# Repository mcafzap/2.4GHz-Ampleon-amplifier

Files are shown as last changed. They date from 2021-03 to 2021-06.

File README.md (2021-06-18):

# This amplifier is based on the Ampleon BCP2425M9X2S250-1 pallet

The bias circuit is taken from Ampleon's application note AN10900. There is an MSP430G2553 processor and an I2C 1.3" OLED display and 2 digital current monitors using the TLI4970. Unfortunately this current measurement device is end-of life, but it remains the best for resolving 6.25mA and measuring up to 25A. The display monitors voltage & current of each stage, sets the bias of each stage and shows the total power used.

Output protection is provided by a 100W isolator from Bert Modderman (pe1rki.com)
A 30v, 10A supply should give about 150W maximum - more than adequate for Q0-100 access. This pallet has 30dB of gain but a pre-amp will likely be required - the Amsat kit or a cheap shielded Chinese type. The circuit board uses an LM2596 dc-dc module. This can supply 12v for fans and/or the pre-amp or any voltage may be set to suit these devices. A lower voltage will lower the stress on the 3.3v linear regulator.

I used Kicad to draw/plot the circuit board and had them manufactured by JLCPCB. The program was written and tested on TI's Code Composer Studio but Energia may be used. 
The metal work was designed on FreeCAD and can be made from stock Al bar (10mm x 20mm) and Al sheet (2mm). The heatspreader is 10mm x 100mm x 72mm Cu. This is mounted on an Al heatsink approximately 250mm x 200mm x 40mm; it does not seem to require any fans.

Remember this is high frequency so everything must be kept short or shielded and properly 50 ohm terminated.

Thanks go to Vincent(M0LCR), Mike(G4VSS) and Brian(G4EWJ) for software/hardware advice but thanks are especially owed to Anthony Tognarelli of Waterfield Electronics Ltd. (waterfieldelectronics.com) for providing the pallets.

If I were to do this again? I'd simply use multi-turn presets to set the bias levels, (10K across a 3.3v supply). Much of the circuitry is concerned with displaying little-used data like power input and bias currents - once set, these are never changed.

vcloseamp
closeAMP
full amp

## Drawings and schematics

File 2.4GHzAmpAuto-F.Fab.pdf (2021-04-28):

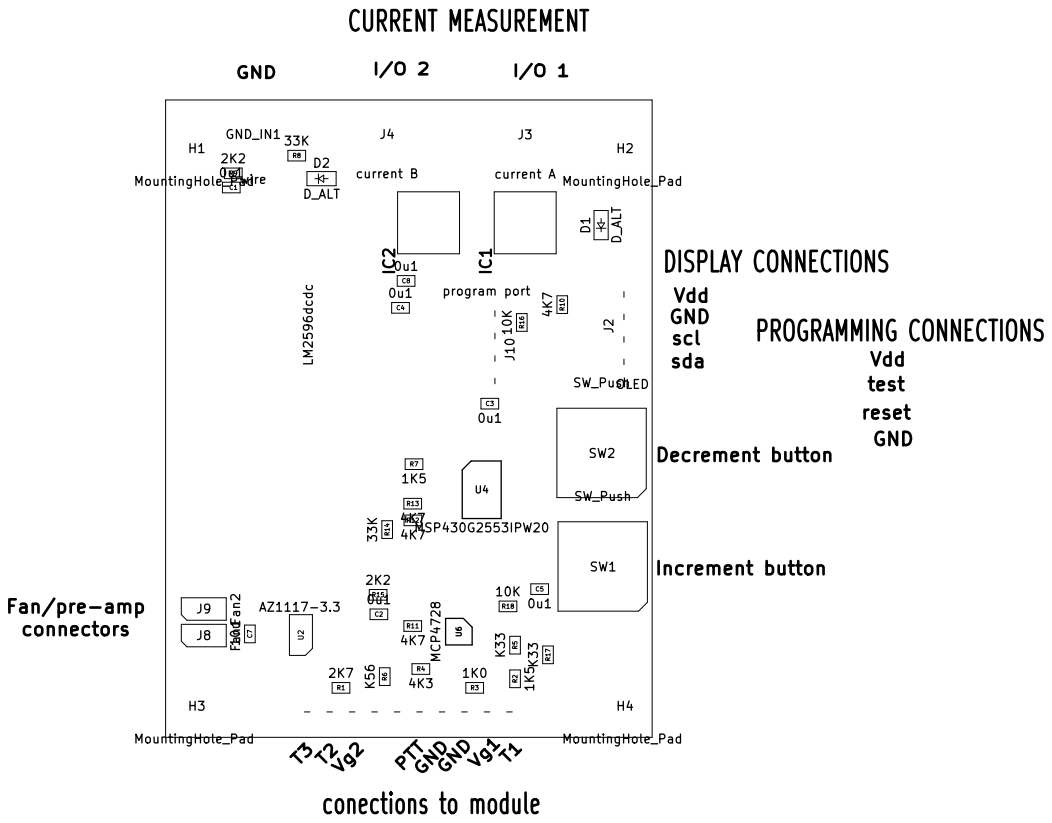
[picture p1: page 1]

Increment button Decrement button

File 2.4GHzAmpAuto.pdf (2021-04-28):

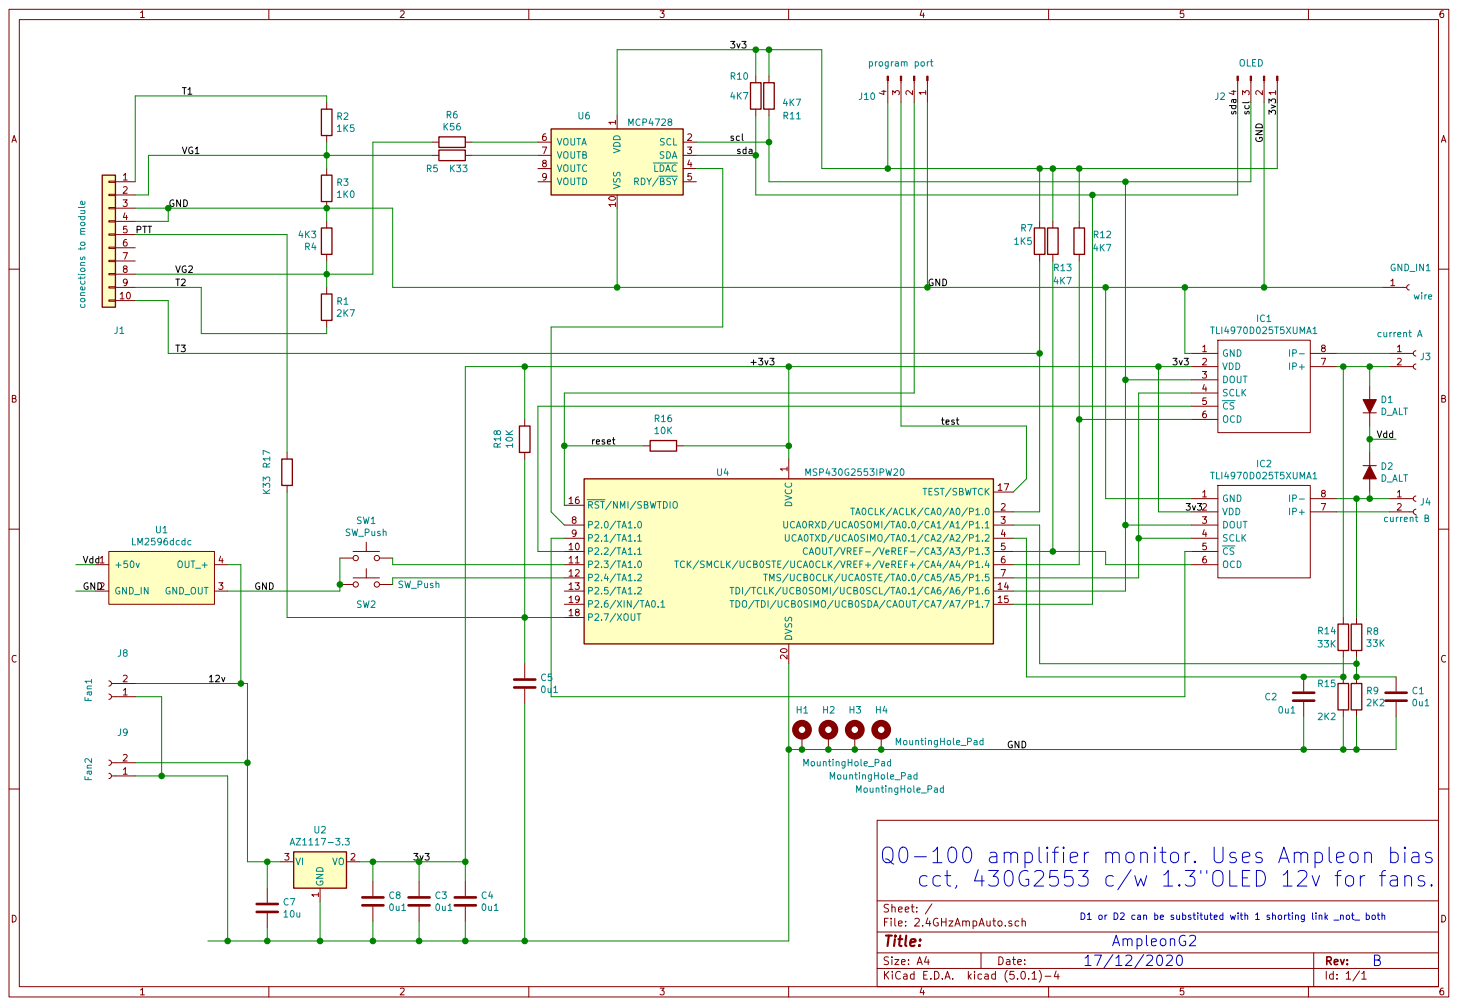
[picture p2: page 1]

1 P2.2/TA1.1 10 P2.3/TA1.0 11 P2.4/TA1.2 12 P2.5/TA1.2 13 TDI/TCLK/UCB0SOMI/UCB0SCL/TA0.1/CA6/A6/P1.6 14 TDO/TDI/UCB0SIMO/UCB0SDA/CAOUT/CA7/A7/P1.7 15 RST/NMI/SBWTDIO 16 TEST/SBWTCK 17 P2.7/XOUT 18 P2.6/XIN/TA0.1 19 TA0CLK/ACLK/CA0/A0/P1.0 2 DVSS 20 UCA0RXD/UCA0SOMI/TA0.0/CA1/A1/P1.1 3 UCA0TXD/UCA0SIMO/TA0.1/CA2/A2/P1.2 4 CAOUT/VREF-/VeREF-/CA3/A3/P1.3 5 TCK/SMCLK/UCB0STE/UCA0CLK/VREF+/VeREF+/CA4/A4/P1.4 6 TMS/UCB0CLK/UCA0STE/TA0.0/CA5/A5/P1.5 7 P2.0/TA1.0 8 P2.1/TA1.1 9 U4 MSP430G2553IPW20 R12

GND 1 VDD 2 DOUT 3 SCLK 4 CS 5 OCD 6

Q0-100 amplifier monitor. Uses Ampleon bias
cct, 430G2553 c/w 1.3"OLED 12v for fans.

File: 2.4GHzAmpAuto.sch Sheet: / GND

AmpleonG2

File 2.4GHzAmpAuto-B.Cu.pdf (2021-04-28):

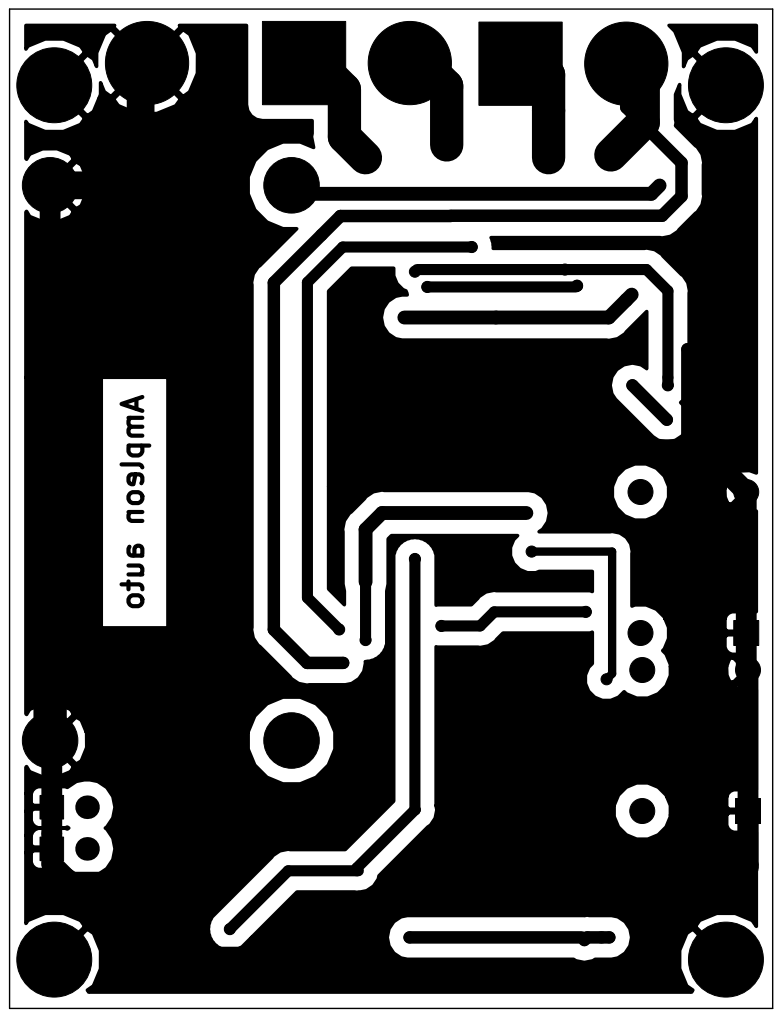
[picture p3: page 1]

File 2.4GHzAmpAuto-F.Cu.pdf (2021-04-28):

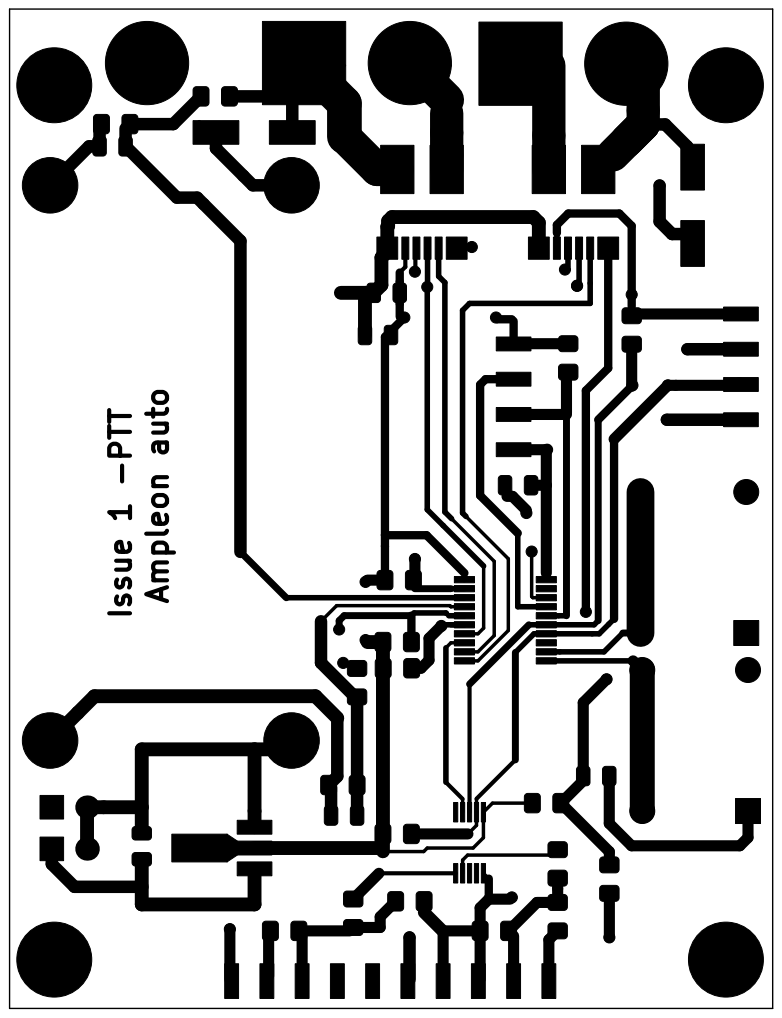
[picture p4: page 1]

Issue 1 -PTT Ampleon auto

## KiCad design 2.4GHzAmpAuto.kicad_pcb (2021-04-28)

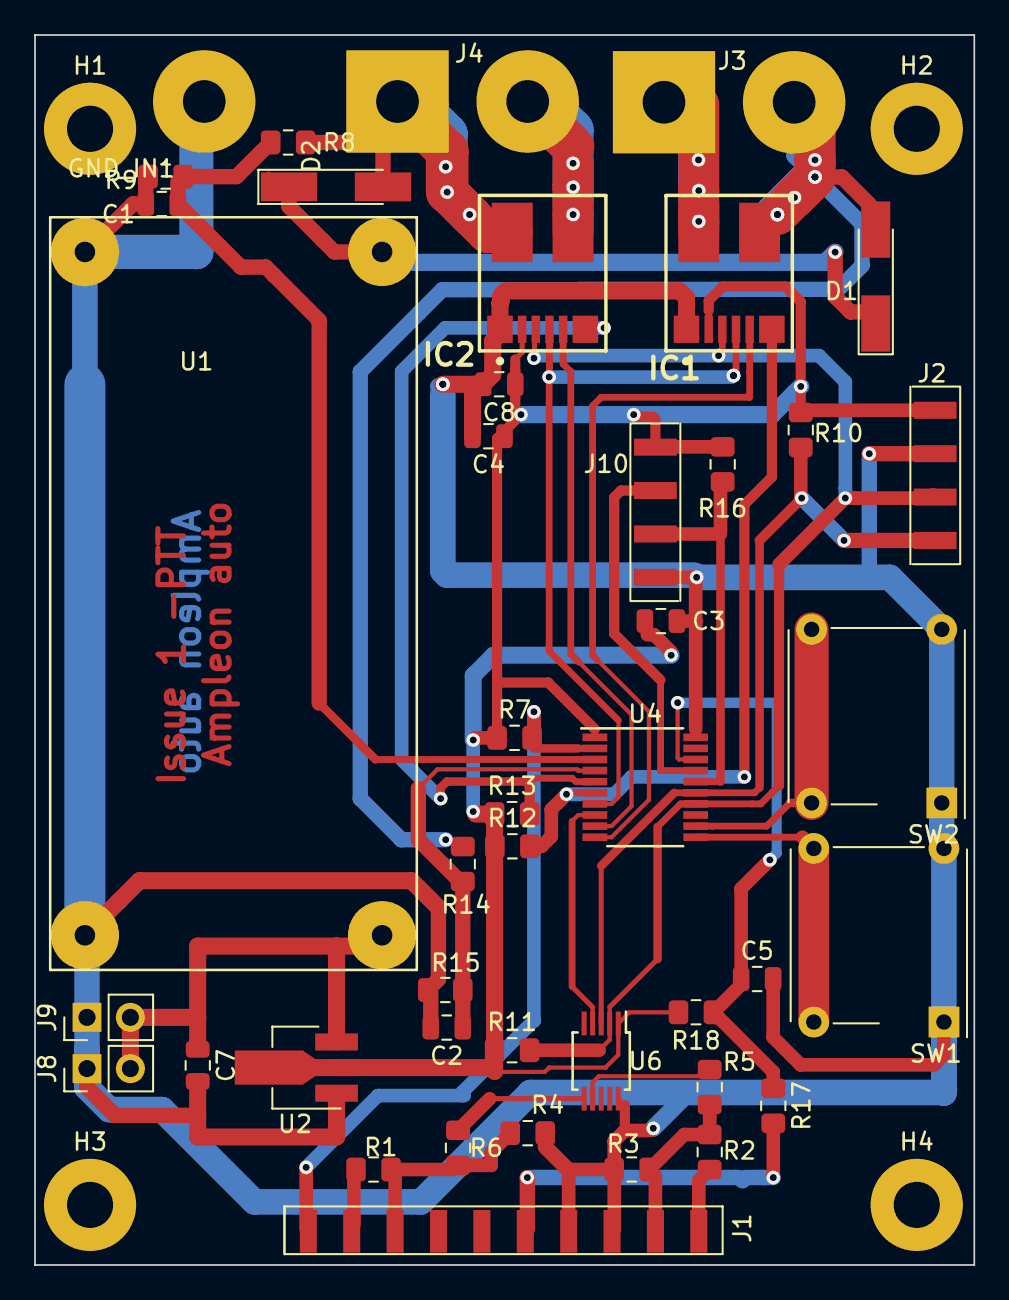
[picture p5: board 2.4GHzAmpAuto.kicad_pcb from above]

Board: 2 copper layers, 55.0 x 72.0 mm, 47 parts (0 on the bottom side), 31 nets.

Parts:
C1, C2, C3, C4, C5, C8: 0u1; C_0805_2012Metric
C7: 10u; C_0805_2012Metric
D1, D2: D_ALT; D_MiniMELF_Handsoldering
GND_IN1: wire; SolderWirePad_1x01_Drill2.5mm
H1, H2, H3, H4: MountingHole_Pad; MountingHole_2.7mm_M2.5_Pad
IC1, IC2: TLI4970D025T5XUMA1; PG-TISON-8-1
J1: conections to module; Harwin_M20-89010xx_1x10_P2.54mm_Horizontal
J2: OLED; 1x04_P2.54mm_Pads
J3: current A; SolderWirePad_1x02_P7.62mm_Drill2.5mm
J4: current B; SolderWirePad_1x02_P7.62mm_Drill2.5mm
J8: Fan1; PinHeader_1x02_P2.54mm_Vertical
J9: Fan2; PinHeader_1x02_P2.54mm_Vertical
J10: program port; 1x04_P2.54mm_Pads
R1: 2K7; R_0805_2012Metric_Pad1.15x1.40mm_HandSolder
R2, R7: 1K5; R_0805_2012Metric_Pad1.15x1.40mm_HandSolder
R3: 1K0; R_0805_2012Metric_Pad1.15x1.40mm_HandSolder
R4: 4K3; R_0805_2012Metric_Pad1.15x1.40mm_HandSolder
R5, R17: K33; R_0805_2012Metric_Pad1.15x1.40mm_HandSolder
R6: K56; R_0805_2012Metric_Pad1.15x1.40mm_HandSolder
R8, R14: 33K; R_0805_2012Metric_Pad1.15x1.40mm_HandSolder
R9, R15: 2K2; R_0805_2012Metric_Pad1.15x1.40mm_HandSolder
R10, R11, R12, R13: 4K7; R_0805_2012Metric_Pad1.15x1.40mm_HandSolder
R16, R18: 10K; R_0805_2012Metric_Pad1.15x1.40mm_HandSolder
SW1, SW2: SW_Push; SW_MEC_5GTH9
U1: LM2596dcdc; LM2596_dc-dc_module
U2: AZ1117-3.3; SOT-89-3_Handsoldering
U4: MSP430G2553IPW20; TSSOP-20_4.4x6.5mm_P0.65mm
U6: MCP4728; MSOP-10_3x3mm_P0.5mm

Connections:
/12v: C7.1, J8.2, J9.2, U1.4, U2.3
/+3v3: C3.1, C4.1, C8.1, IC1.2, IC2.2, J2.1, J10.4, R7.1, R10.1, R11.1, R12.1, R13.1, R16.1, R18.2, U2.2, U4.1, U6.1
/GND: C1.2, C2.2, C3.2, C4.2, C5.2, C7.2, C8.2, GND_IN1.1, H1.1, H2.1, H3.1, H4.1, IC1.1, IC2.1, J1.3, J1.4, J2.2, J8.1, J9.1, J10.1, R3.2, R4.2, R9.2, R15.2, SW1.1, SW2.1, U1.2, U1.3, U2.1, U4.20, U6.10
/PTT: J1.5, R17.2
/T1: J1.1, R2.1
/T2: J1.9, R1.2
/T3: J1.10, R7.2, U4.2
/VG1: J1.2, R2.2, R3.1, R5.2
/VG2: J1.8, R1.1, R4.1, R6.2
/Vdd: D1.1, D2.1, U1.1
/reset: J10.2, R16.2, U4.16
/scl: IC1.3, IC2.3, J2.3, R11.2, U4.14, U6.2
/sda: J2.4, R10.2, U4.15, U6.3
/test: J10.3, U4.17
unnamed: C1.1, R8.2, R9.1, U4.3
unnamed: C2.1, R14.2, R15.1, U4.4
unnamed: C5.1, R17.1, R18.1, U4.18
unnamed: D1.2, IC1.7, J3.2, R14.1
unnamed: D2.2, IC2.8, J4.1, R8.1
unnamed: IC1.4, IC2.4, U4.7
unnamed: IC1.5, U4.10
unnamed: IC1.6, R12.2, U4.6
unnamed: IC1.8, J3.1
unnamed: IC2.5, U4.9
unnamed: IC2.6, R13.2, U4.5
unnamed: IC2.7, J4.2
unnamed: R5.1, U6.7
unnamed: R6.1, U6.6
unnamed: SW1.2, U4.11
unnamed: SW2.2, U4.12
unnamed: U4.8, U6.4

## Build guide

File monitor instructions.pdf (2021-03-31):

## Amplifier Monitor

The functon of this circuit is to set the bias currents of the 2 actve devices on the Ampleon BPC2425M9X2S250 pallet and monitor the current and power taken by this amplifer and provide a 12 volt supply for 2 x 50mm fans forced cooling. Some of the circuit is taken from the Ampleon datasheet.
There is a 1.3” OLED display and 2 pushbutons. The display has 2 modes, normally it shows the voltage and current being taken by the module along with the total input power. When setng the bias currents, one of the 2 bias levels is shown instead of the power.
The current monitors are fully isolated and can be connected in either polarity. They have a range of +/-25A and the resoluton is 6.25mA so the display will change in about 6mA steps (6, 12, 18, 25 ...).

Wiring.
At one end the connectons are arranged to provide a one-to-one correlaton to the module. The board needs a ground (0v) connecton; it can take its supply voltage (30v) from either current monitor. These current monitors may be connected in any polarity and either may be used for the 2 stages.

Removal of Ofset.
At frst switch-on there may be an ofset of 1 or 2 bits which will manifest itself as +/-0.006 or 0.012; this can be removed (only once per switch-on) by pressing both butons together.

Bias setng mode.
This is entered by holding down one of the butons whilst applying the power. Which buton is held is down determines which bias setng will be adjusted.
The bias levels can range from 0 to 3.300 volts in 1mV steps. Note that there is a resistor divider and thermistor circuit before this voltage goes to the module, so this is not the value output to the module.
Pressing any buton will either increment or decrement the bias value;

holding the buton will cause the value to change rapidly. Monitor the current value whilst adjustng the bias untl it is set correctly 50mA for the frst stage and 25mA the output stage. Do not turn-of the circuit untl the display reverts to the Input Power (there is a 10 second tmeout) as the bias value is not saved untl then.

Push-to-Talk.
An additonal switch may be used to disable the bias outputs. This requires a connecton to pin 18 of the microprocessor, a series resistor and a decoupling capacitor.
However, the quiescent power is only 2 wats so this may be unnecessary.

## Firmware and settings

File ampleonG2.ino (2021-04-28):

#include <SPI.h>
#include <Wire.h>
#include <U8x8lib.h>
#include <OneWire.h>
#include "MspFlash.h"

#define flash SEGMENT_D
// Pins usage
int CS1 = P2_1;
int CS2 = P2_2;
int SCL = P1_6;
int SDA = P1_7;

int ThermistorPin = A0;
int VoltagePinA = A1;
int VoltagePinB = A2;
const int Button1 = P2_3;
const int Button2 = P2_4;
const int Button3 = 18; //P2_7 on MSP430G2553

const uint16_t degree[] = { 576, 563, 550, 537, 524, 511, 498, 485, 473, 460,
                            448, 435, 423, 412, 400, 388, 377, 366, 355, 344,
                            334, 324, 314, 304, 295, 285, 276, 259, 250, 242,
                            234, 227, 219, 212, 205, 198, 192, 185, 179, 173,
                            167, 161, 156, 151, 146, 141, 137, 132, 128, 124,
                            119, 116, 112, 108, 105, 101, 98, 95, 92, 89, 86,
                            83, 81, 78, 76, 73, 71, 69, 66, 65, 62, 60, 59, 57,
                            55 };
// 76 values 20 - 95C
//const uint16_t degree[] = { 511, 448, 388, 334, 285, 242, 205, 173, 146, 124,
//                            105, 89, 76, 65, 55 };
// 15 values
// 21 degrees = (511-448/5) + 511 ~ 498.4
// Variables
uint8_t x, neg;
uint8_t setMode = 0, zeroBias = 0, offsetRemoval = 0;
char SerBuf[8];
//unsigned char p[4];
//unsigned char q, r, s;
int8_t i;
uint16_t Vth, Vhi;
uint16_t I1 = 0x1000, I2 = 0x1000;
union
{
    struct
    {
        uint16_t I1_offset;
        uint16_t I2_offset;
    } Offset;
    unsigned char p[4];
} Fdata;

uint8_t volt, temp, C1Amps, C2Amps;
uint16_t values[8];
uint16_t Vg2, Vg1, status;
uint8_t hiByte, loByte;
uint16_t AverageI1, dataOut;
uint16_t Vx, AccV = 0x2810, AccT;
uint8_t R2;
uint16_t C1, Acc1 = 0x3000;
uint16_t C2, Acc2 = 0x3000;
uint16_t POWER;
uint32_t timeout;

void wrtEEP4728(void);

#define WIRE_INTERFACES_COUNT 2

U8X8_SH1106_128X64_NONAME_HW_I2C u8x8(/* reset=*/U8X8_PIN_NONE);
//U8X8_SSD1306_128X64_NONAME_HW_I2C u8x8(/* reset=*/U8X8_PIN_NONE);
//U8X8_SSD1305_128X64_ADAFRUIT_HW_I2C u8x8(/* reset=*/U8X8_PIN_NONE);
//U8X8_SSD1305_128X64_NONAME_HW_I2C u8x8(/* reset=*/ U8X8_PIN_NONE);
//U8X8_SSD1325_128X64_NONAME_HW_I2C([/* reset=*/ U8X8_PIN_NONE);

OneWire M1(P1_4);
OneWire M2(P1_3);

void setup()

{ // recover offsets...
    Flash.read(flash, &Fdata.p[0], 4);
// these might  be 0xffff if a new chip, check and 0?
    if (Fdata.Offset.I1_offset == 0xffff)
        Fdata.Offset.I1_offset = 0;
    if (Fdata.Offset.I2_offset == 0xffff)
        Fdata.Offset.I2_offset = 0;
    //    data.I1_offset = (p[0]<<8) | p[1];
//    data.I2_offset = (p[2]<<8) | p[3];
    x = 0;
    P1SEL = 0;
    P2SEL = 0; // all I/O lines
    P1OUT = 0x00;
    P1DIR = 0xFF; // all outputs
    P2OUT = 0x00;
    P2DIR = 0xFF; // all outputs

    pinMode(CS1, OUTPUT);
    pinMode(CS2, OUTPUT);
    pinMode(Button1, INPUT_PULLUP);
    pinMode(Button2, INPUT_PULLUP);
    pinMode(Button3, INPUT_PULLUP);
    pinMode(ThermistorPin, INPUT);

    digitalWrite(CS1, 1); //disable one current sensor
    digitalWrite(CS2, 1); //disable the other current sensor
    analogReference (INTERNAL2V5);

    Vx = txTwo16(0x8000);
    delayMicroseconds(30);
    Vx = txTwo16(0x8000);
    Vx |= 0x0f80;
    POWER = txTwo16(0x8001);
    delayMicroseconds(30);
    POWER = txTwo16(Vx);
    delayMicroseconds(30);

    Vx = txOne16(0x8000); //Temporary usage of 'Vx'
    delayMicroseconds(30);
    Vx = txOne16(0x8000);
    Vx |= 0x0f80;
    POWER = txOne16(0x8001); //Temporary usage of 'POWER'
    delayMicroseconds(30);
    POWER = txOne16(Vx);
    delayMicroseconds(30);

    pinMode(SCL, INPUT_PULLUP); // Attempt to recover from I2C crash...
    pinMode(SDA, INPUT_PULLUP);
    int8_t ClockCount = 20, counter;
    while ((digitalRead(SDA) == 0) && (ClockCount > 0))
    {
        pinMode(SCL, INPUT);
        pinMode(SCL, OUTPUT);
        delayMicroseconds(10);
        pinMode(SCL, INPUT);
        pinMode(SCL, OUTPUT);
        delayMicroseconds(10);
        int count = 20;
        while ((digitalRead(SCL) == 0) && (counter > 0))
        {
            counter--;
            delay(100);
        }
    }
    pinMode(SDA, INPUT);
    pinMode(SDA, OUTPUT);
    delayMicroseconds(10);
    pinMode(SDA, INPUT);
    pinMode(SDA, INPUT_PULLUP);
    delayMicroseconds(10);
    pinMode(SDA, INPUT);
    pinMode(SCL, INPUT);

    Wire = TwoWire(0);

    u8x8.begin();
    u8x8.setFont(u8x8_font_5x7_r);    // Normal 1:1 pixel scale
    u8x8.setContrast(8);
    u8x8.draw2x2String(0, 0, "WARC AMP");
    u8x8.draw2x2String(2, 3, "Q0-100");
    u8x8.draw2x2String(1, 6, "Monitor");
    u8x8.display();
    delay(2000);
    setMode = 0;

    u8x8.clear();
    u8x8.drawString(0, 0, "V              C");
    u8x8.draw2x2String(2, 2, "I1  I2");

    u8x8.drawString(0, 6, "    Input Watts");
    Wire.endTransmission(1);

    zeroBias = 1;  // Zero bias voltages on switch-on!
    Vg1 = 0;
    Vg2 = 0;

    wrtVol4728(); //just do a volatile write for now - write to EEPROM on timeout

//    read4728(); // recover V bias settings
//    Vg2 = values[1];
//    Vg1 = values[3];
//    reset4728();
    if ((digitalRead(Button1) == 0) ||(digitalRead(Button2) == 0))
    {
        read4728(); // bias about to be set, recover V bias settings
        Vg2 = values[1];
        Vg1 = values[3];
        if (Vg1 < 1500) Vg1 = 1500;
        if (Vg2 < 1500) Vg2 = 1500;
        reset4728();
    }
    if (digitalRead(Button1) == 0)
    {
        setMode = 1;
        u8x8.drawString(0, 6, "Vg1 Bias setting");
    }

    if (digitalRead(Button2) == 0)
    {
        setMode = 2;
        u8x8.drawString(0, 6, "Vg2 Bias setting");
    }

    while ((digitalRead(Button1) == 0) || (digitalRead(Button2) == 0))
        timeout = millis();
    //await release so as not to alter values
}

void loop()
{
    Vx = txTwo16(0x8000);
    delayMicroseconds(30);
    Vx = txTwo16(0x8000);
    Vx |= 0x0f80;
    POWER = txTwo16(0x8001);
    delayMicroseconds(30);
    POWER = txTwo16(Vx);
    delayMicroseconds(30);

    Vx = txOne16(0x8000); //Temporary usage of 'Vx'
    delayMicroseconds(30);
    Vx = txOne16(0x8000);
    Vx |= 0x0f80;
    POWER = txOne16(0x8001); //Temporary usage of 'POWER'
    delayMicroseconds(30);
    POWER = txOne16(Vx);
    delayMicroseconds(30);
// Obtain current values
    SPI.begin();
    SPI.end();
    SPI.begin();
    SPI.setBitOrder(MSBFIRST);
    SPI.setDataMode(SPI_MODE1);
    SPI.setClockDivider(SPI_CLOCK_DIV16);

    digitalWrite(CS1, 0);
    delayMicroseconds(2);
    status = SPI.transfer16(0xffff);
    delayMicroseconds(10);
    digitalWrite(CS1, 1);
    if (!(status & 0x8000))
    {
        I1 = status & 0x1fff;
// exponential average routine
        Acc1 += I1;
        I1 = Acc1 >> 2; // /4
        Acc1 = I1 << 2; // x4
        Acc1 -= I1;     // x3
    }

    digitalWrite(CS2, 0);
    delayMicroseconds(2);
    status = SPI.transfer16(0xffff);
    delayMicroseconds(10);
    digitalWrite(CS2, 1);
    SPI.end();
    if (!(status & 0x8000)) // If not a status byte
    {
        I2 = status & 0x1fff;
// exponential average routine
        Acc2 += I2;
        I2 = Acc2 >> 2; // /4
        Acc2 = I2 << 2; // x4
        Acc2 -= I2;     // x3
    }
//
    C1 = I1 + Fdata.Offset.I1_offset; //MUST sort out negative sign!!!!!!!!!!!!!!!!!!!!!!!!!!!!!!!!!!!!
    x = 1;
    neg = ' ';
    if (C1 < 0x1000)
    {
        C1 = ~C1 + 1; //2's complement
        neg = '-';
    }
    C1 &= 0x0FFF;
// Make all values positive (doesn't matter about current direction)
    displayRight(C1);  // move into SerBuf...
    SerBuf[0] = neg;

    C2 = I2 + Fdata.Offset.I2_offset;
    neg = ' ';
    if (C2 < 0x1000)
    {
        C2 = ~C2 + 1; //2's complement
        neg = '-';
    }
    C2 &= 0x0FFF;

// Make all values positive (doesn't matter about current direction)
    u8x8.drawString(0, 4, SerBuf);
    displayRight(C2);
    SerBuf[0] = neg;
    u8x8.drawString(9, 4, SerBuf);

    Vhi = analogRead(VoltagePinA);
    if (Vhi < 100)
        Vhi = analogRead(VoltagePinB); // read other voltage input if this is zero...
// exponential average routine
    AccV = AccV + Vhi;
    Vhi = AccV >> 4;    // /8

    AccV = Vhi << 4;    // x8
    AccV -= Vhi;        // x7

    Vx = (Vhi * 55) >> 7; //calc: (2.5/1023) * (33+2)/2 * reading (ten times) ;
    itoa(Vx, SerBuf, 10); //Vx is in hundreths, 30v = 300. Factor: 0.42766

    SerBuf[3] = SerBuf[2];
    SerBuf[2] = '.';
    SerBuf[4] = '\0';
    u8x8.drawString(2, 0, SerBuf);

    Vth = analogRead(ThermistorPin);
    AccT = AccT + Vth;
    Vth = AccT >> 4;    // /16

    AccT = Vth << 4;    // x16
    AccT -= Vth;        // x15

// simple look-up for temperature - not enough resources
    R2 = 20; //for interpolation improvement (?)
    x = 0;
    while ((Vth < degree[x]) && (x < 76)) //15 otherwise
    {
        R2++;
        x++;
    }

    itoa(R2, SerBuf, 10);    // then write out temperature
    u8x8.drawString(12, 0, SerBuf);

    if (setMode == 0) // If NOT setting biases...
    {
// Calculation is (|c1|+|c2|) * 0.00625 * V/10 (V is 10 times value)
        POWER = ((uint32_t) (C1 + C2) * Vx) / 1600;
        rightJustify(POWER);
        u8x8.drawString(3, 7, SerBuf);
        u8x8.display();
        delay(50);
    }
    if (setMode > 0)
    {
        if (millis() - timeout > 10000) //10 second timeout
        {
            setMode = 0;
            wrtEEP4728(); // Save bias settings to EEPROM
            u8x8.drawString(0, 6, "    Input Watts ");
        }

        if ((digitalRead(Button1) == 0))
        {
            timeout = millis();
            if (setMode == 1)
            {
                Vg1++;
                if (Vg1 > 4095)
                    Vg1 = 4095; //no roll-over
            }
            else
            {
                Vg2++;
                if (Vg2 > 4095)
                    Vg2 = 4095; //no roll-over
            }
        }

        if (digitalRead(Button2) == 0)
        {
            timeout = millis();
            if (setMode == 1)
            {
                if (Vg1 == 0)
                    Vg1 = 1; //no roll-under
                Vg1--;
            }
            else
            {
                if (Vg2 == 0)
                    Vg2 = 1; //no roll-under
                Vg2--;

            }
        }
        wrtVol4728(); // output bias settings
        if (setMode == 1)
        {
            rightJustify(Vg1);
        }
        else
        {
            rightJustify(Vg2);
        }
        u8x8.drawString(3, 7, SerBuf);
        u8x8.display();
        delay(100); //
    }

    if (setMode == 0)
    {
        // Offset Removal ********************************
        // both buttons down to store offsets

        if ((digitalRead(Button1) == 0) && (digitalRead(Button2) == 0)
                && (offsetRemoval == 0) && (zeroBias == 1)) // store I offsets
        {
            Fdata.Offset.I1_offset = 0x1000 - I1; // say 0x0ffe -> 0xfffe or -2
            Fdata.Offset.I2_offset = 0x1000 - I2; // say 0x1003 -> 0x0003 or +3
            offsetRemoval = 1; // Now write to Flash
//        Fdata.p[0] = I1_offset >> 8;
//        Fdata.p[1] = I1_offset & 0xff;
//        Fdata.p[2] = I2_offset >> 8;
//        Fdata.p[3] = I2_offset & 0xff;
            Flash.erase(flash);
            Flash.write(flash, &Fdata.p[0], 4);
//        Flash.write(flash+1, &q, 1);
//        Flash.write(flash+2, &r, 1);
//        Flash.write(flash+3, &s, 1);
// No need to wait!        while ((digitalRead(Button1) == 0) || (digitalRead(Button2) == 0))
            ;// now wait here for release of both buttons
        }

        //********************PTT SECTION********************
        // If not setting bias voltages, zero the bias voltages until PTT is pulled low
        // If the first condition is invalid, the second may also be, so the entire section is skipped
        // To make PTT function, Button3 must be held down at least once after switch-on.
        if (digitalRead(Button3) == 0)
        {

            if (zeroBias == 1)
            {
                zeroBias = 0; // do general reset to restore eeprom values to outputs
                reset4728();
            }
        }
        else // restore values if we've been here...
        if (zeroBias == 0) // zero bias voltage
        {
            zeroBias = 1;
            Vg1 = 0;
            Vg2 = 0;

            wrtVol4728(); //just do a volatile write for now - write to EEPROM on timeout
        } // end of PTT section

    } // end of 'mode = 0' sections (PTT & bias removal)
//    Wire.endTransmission();
} //main Energia loop

// subroutines....
// write to MCP4728
void wrtEEP4728()
{ //mode determines whether to write to volatile or non-volatile memory
    Wire = TwoWire(0);
    Wire.beginTransmission(0x60);
    Wire.write(0x50); //multi-write command

    hiByte = Vg2 >> 8;
    hiByte &= 0x0f; //use internal reference and x2 (0x90)
    hiByte |= 0x90; // or Vcc and x 1 (0x00)
    loByte = Vg2 & 0x00ff; // This is VG1
    Wire.write(hiByte); //send value
    Wire.write(loByte); //send value
// prepare values (16-bit -> 2x8-bit)
    hiByte = Vg1 >> 8;
    hiByte &= 0x0f;
    hiByte |= 0x90; //write to channel B, C & D
    loByte = Vg1 & 0x00ff; // D is VG2
    Wire.write(hiByte); //send value
    Wire.write(loByte); //send value

    Wire.write(hiByte); //send value
    Wire.write(loByte); //send value

    Wire.write(hiByte); //send value
    Wire.write(loByte); //send value
    Wire.endTransmission(1);
}

void wrtVol4728(void)
{ //Writes values to device, but only into volatile memory
    Wire = TwoWire(0);
    Wire.beginTransmission(0x60);
    hiByte = Vg2 >> 8;
    hiByte &= 0x0f; //use internal reference and x2 (0x90)
    loByte = Vg2 & 0x00ff; // This is VG1
    Wire.write(hiByte); //send value
    Wire.write(loByte); //send value
    hiByte = Vg1 >> 8;
    hiByte &= 0x0f;
    loByte = Vg1 & 0x00ff; // D is VG2
    Wire.write(hiByte); //send value
    Wire.write(loByte); //send value
    Wire.write(hiByte); //send value
    Wire.write(loByte); //send value
    Wire.write(hiByte); //send value
    Wire.write(loByte); //send value
    Wire.endTransmission(1);
}

void reset4728()
{
    Wire = TwoWire(0);
    Wire.beginTransmission(0x00);
    Wire.write(0x06);
    Wire.endTransmission(1);
}

void read4728(void)
{
    Wire.beginTransmission(0x60);
    Wire.requestFrom(0x60, 24);
    while (Wire.available())
    {
        for (x = 0; x < 8; x++)
        {
            hiByte = Wire.read();  // discard - contains some device ID
            hiByte = Wire.read();  // Reads high part from the register
            loByte = Wire.read();  // Reads lsb from the register
            values[x] = word((hiByte & 0x0f), loByte); //combine & store
        }
    }
    Wire.endTransmission(1);
}

// The  following are for setting the bandwidth of the current sensors
// this value is ephemeral (without 20v and associated switching
uint16_t txOne16(uint16_t dataIn)
{
    dataOut = 0;
    for (i = 15; i >= 0; i--)
    {
        write1_bit((dataIn >> i) & 0x01);
        dataOut |= (read1_bit()) << i;
    }
    delayMicroseconds(50);
    return dataOut;
}

uint16_t txTwo16(uint16_t dataIn)
{
    {
        dataOut = 0;
        for (i = 15; i >= 0; i--)
        {
            write2_bit((dataIn >> i) & 0x01);
            dataOut |= (read2_bit()) << i;
        }
        delayMicroseconds(50);
        return dataOut;
    }
}

uint8_t read1_bit()
{
    return !(M1.read_bit());
}

void write1_bit(uint8_t value)
{
    M1.write_bit(!value);
}

uint8_t read2_bit()
{
    return !(M2.read_bit());
}

void write2_bit(uint8_t value)
{
    M2.write_bit(!value);
}

void displayRight(uint16_t d) //adjust reading and right justify current values
{
//    d = ((uint32_t)d * 100) >> 4; // multiply by 6.25
    d = d * 6.25;
    rightJustify(d);
    if (SerBuf[4] == ' ')
    {
        SerBuf[4] = '0';
        if (SerBuf[5] == ' ')
            SerBuf[5] = '0';
    }
    SerBuf[1] = SerBuf[2];
    SerBuf[2] = SerBuf[3];
    SerBuf[3] = '.';
    if (SerBuf[2] == ' ')
        SerBuf[2] = '0';
}

void rightJustify(uint16_t f)
{
    for (x = 1; x < 8; x++)
        SerBuf[x] = '\0'; //clear SerBuf[]
    itoa(f, SerBuf, 10);
    while (SerBuf[6] == '\0')
    {
        for (x = 6; x > 0; x--)
            SerBuf[x] = SerBuf[x - 1];
        SerBuf[0] = ' ';
    }
}
